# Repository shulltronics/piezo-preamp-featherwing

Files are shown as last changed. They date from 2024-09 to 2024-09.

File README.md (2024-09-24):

Piezo Preamp FeatherWing
=========================================

### By Carsten Thue-Bludworth, September 2024

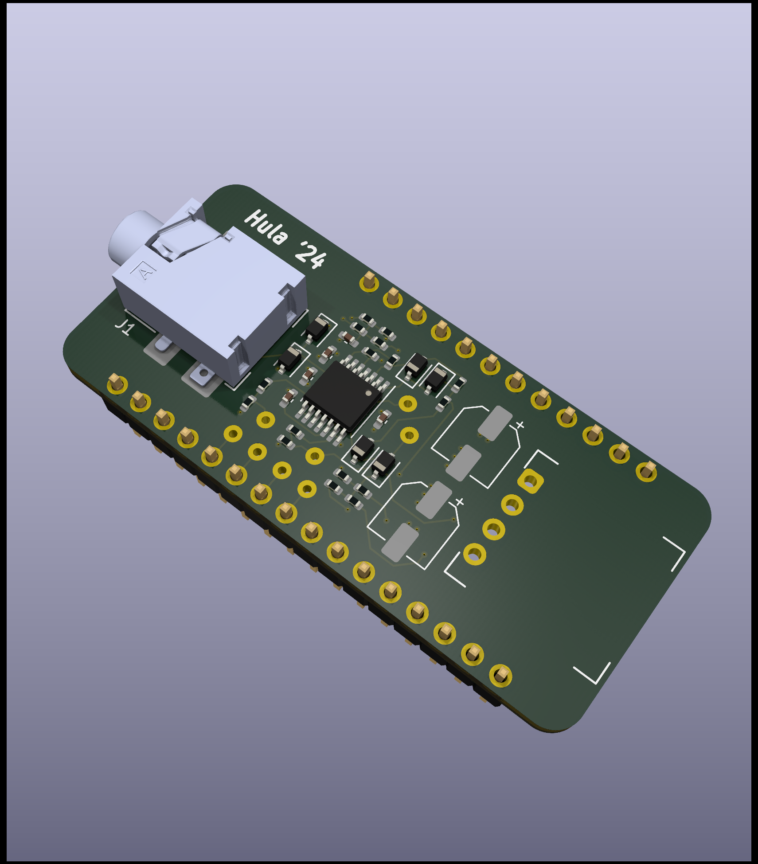
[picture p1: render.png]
board render


This featherwing provides a high-impedance gain stage and a simple envelope follower for piezo contact microphones.

The piezo is connected via a standard 3.5mm TRS shielded audio connector with the following pinout:
 - Tip: piezo signal
 - Ring: piezo ground
 - Sleeve: cable shield (not connected on piezo end)

The board requires a bipolar +12V/-12V power supply, provided via a 4pos Molex SL connector with the following pinout:
 - 1: +12V
 - 2: GND
 - 3: -12V
 - 4: signal out (default to unattenuated envelope follower signal).

Jumpers and plated holes are provided to configure which signals are sent to which pins.
* By default, the SL connector gets the unattenuated envelope follower signal.
* By default, no analog pins on the feather headers are connected. Use wire jumpers to connect signals to the analog pins you want to use.
* Jumpers can configure the amplifier stage gain, as well as the envelope follower decay time. By default, the gain is 100x and the decay is set with a 270k resistor.

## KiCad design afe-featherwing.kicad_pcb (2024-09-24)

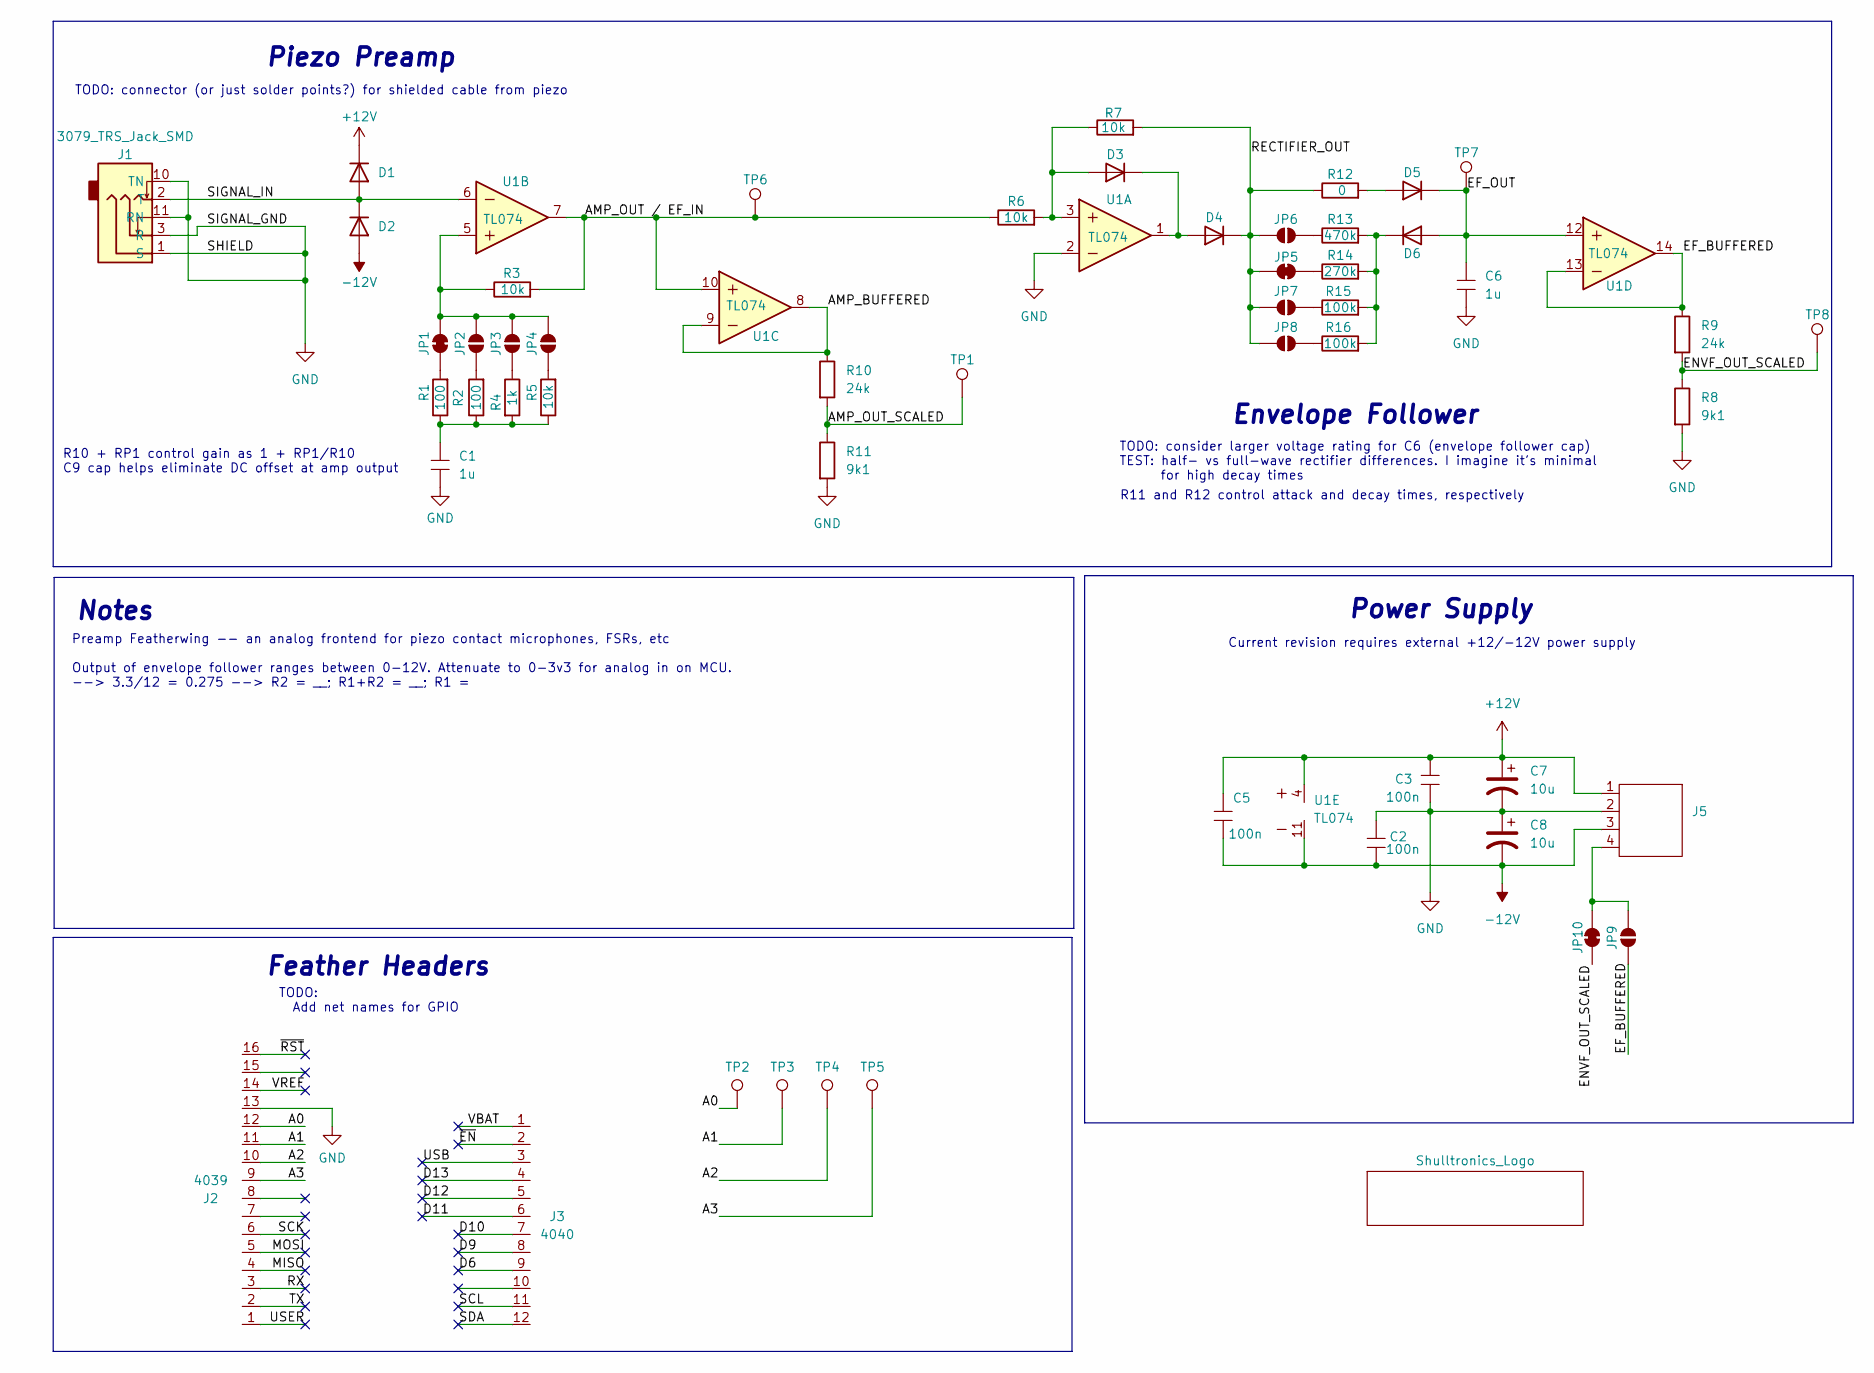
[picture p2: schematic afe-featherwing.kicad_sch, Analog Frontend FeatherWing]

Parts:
C1, C6: 4013_Capacitor_1u_16V_0402; C_0402_HandSolder
C2, C3, C5: 3089_Capacitor_100n_16V_0402; C_0402_HandSolder
C7, C8: 4031_Capacitor_10u_35V_SMD; 3088_Capacitor_10u_50V_SMD
D1, D2, D3, D4, D5, D6: 1N4148W; D_SOD-323
J1: 3079_TRS_Jack_SMD
J2: 4039_Header_Male_Vert_16pin_0.1in; 4039_Header_16pos_2.54mm
J3: 4040_Header_Male_Vert_12pin_0.1in; 4040_Header_12pos_2.54mm
J5: 3033_Connector_SL_4pos_RA; 3033_Molex_SL_4pos_RA
JP1: 100; SolderJumper-2_P1.3mm_Bridged_Pad1.0x1.5mm
JP2: 100; SolderJumper-2_P1.3mm_Open_TrianglePad1.0x1.5mm
JP3: 1k; SolderJumper-2_P1.3mm_Open_TrianglePad1.0x1.5mm
JP4: 10k; SolderJumper-2_P1.3mm_Open_TrianglePad1.0x1.5mm
JP5: 270k; SolderJumper-2_P1.3mm_Bridged_Pad1.0x1.5mm
JP6: 470k; SolderJumper-2_P1.3mm_Open_TrianglePad1.0x1.5mm
JP7, JP8: 100k; SolderJumper-2_P1.3mm_Open_TrianglePad1.0x1.5mm
JP9: EF_BUF; SolderJumper-2_P1.3mm_Open_TrianglePad1.0x1.5mm
JP10: EF_ATN; SolderJumper-2_P1.3mm_Bridged_Pad1.0x1.5mm
L1: Shulltronics_Logo
R1, R2: 4038_Resistor_SMD_100_0.125W_1%; RES-0402
R3, R5, R6, R7: 4008_Resistor_SMD_10k_0.125W_1%; RES-0402
R4: 4010_Resistor_SMD_1k_0.125W_1%; RES-0402
R8, R11: 4082_Resistor_SMD_9k1_1/16W_1%; RES-0402
R9, R10: 4083_Resistor_SMD_24k_1/16W_1%; RES-0402
R12: 4021_Resistor_SMD_Jumper; RES-0402
R13: 4080_Resistor_SMD_470k_0.125W_1%; RES-0402
R14: 4019_Resistor_SMD_270k_0.125W_1%; RES-0402
R15, R16: 4017_Resistor_SMD_100k_0.125W_1%_1; RES-0402
TP1: AMP_ATN; TestPoint_THTPad_D1.5mm_Drill0.7mm
TP2: A0; TestPoint_THTPad_D1.5mm_Drill0.7mm
TP3: A1; TestPoint_THTPad_D1.5mm_Drill0.7mm
TP4: A2; TestPoint_THTPad_D1.5mm_Drill0.7mm
TP5: A3; TestPoint_THTPad_D1.5mm_Drill0.7mm
TP6: AMP_OUT; TestPoint_THTPad_D1.5mm_Drill0.7mm
TP7: EF_BUF; TestPoint_THTPad_D1.5mm_Drill0.7mm
TP8: EF_ATN; TestPoint_THTPad_D1.5mm_Drill0.7mm
U1: 3099_TL074CPW_SMD; 3099_TL074CPW_TSSOP14

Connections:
+12V: C3.2, C5.2, C7.1, D1.1 (K), J5.1, U1.4 (VCC)
-12V: C2.1, C5.1, C8.2, D2.2 (A), J5.3, U1.11 (VEE)
/A0: J2.12, TP2.1
/A1: J2.11, TP3.1
/A2: J2.10, TP4.1
/A3: J2.9, TP5.1
/AMP_BUFFERED: R10.1, U1.8 (3OUT), U1.9 (3IN-)
/AMP_OUT / EF_IN: R3.2, R6.1, TP6.1, U1.7 (2OUT), U1.10 (3IN+)
/AMP_OUT_SCALED: R10.2, R11.1, TP1.1
/D6: J3.9
/D9: J3.8
/D10: J3.7
/D11: J3.6
/D12: J3.5
/D13: J3.4
/EF_BUFFERED: JP9.1 (A), R9.1, U1.13 (4IN-), U1.14 (4OUT)
/EF_OUT: C6.2, D5.1 (K), D6.2 (A), TP7.1, U1.12 (4IN+)
/ENVF_OUT_SCALED: JP10.1 (A), R8.1, R9.2, TP8.1
/MISO: J2.4
/MOSI: J2.5
/RECTIFIER_OUT: D4.1 (K), JP5.1 (A), JP6.1 (A), JP7.1 (A), JP8.1 (A), R7.2, R12.1
/RX: J2.3
/SCK: J2.6
/SCL: J3.11
/SDA: J3.12
/SIGNAL_IN: D1.2 (A), D2.1 (K), J1.2 (T), U1.6 (2IN-)
/TX: J2.2
/USB: J3.3
/USER: J2.1
/VBAT: J3.1
/VREF: J2.14
/~EN: J3.2
/~RST: J2.16
GND: C1.1, C2.2, C3.1, C6.1, C7.2, C8.1, J1.1 (S), J1.3 (R), J1.10 (TN), J1.11 (RN), J2.13, J5.2, R8.2, R11.2, U1.2 (1IN-)
unnamed: C1.2, R1.1, R2.1, R4.2, R5.1
unnamed: D3.2 (A), R6.2, R7.1, U1.3 (1IN+)
unnamed: D3.1 (K), D4.2 (A), U1.1 (1OUT)
unnamed: D5.2 (A), R12.2
unnamed: D6.1 (K), R13.2, R14.2, R15.2, R16.2
unnamed: JP1.1 (A), R1.2
unnamed: JP1.2 (B), JP2.2 (B), JP3.2 (B), JP4.2 (B), R3.1, U1.5 (2IN+)
unnamed: JP2.1 (A), R2.2
unnamed: JP3.1 (A), R4.1
unnamed: JP4.1 (A), R5.2
unnamed: JP5.2 (B), R14.1
unnamed: JP6.2 (B), R13.1
unnamed: JP7.2 (B), R15.1
unnamed: JP8.2 (B), R16.1
unnamed: J5.4, JP9.2 (B), JP10.2 (B)

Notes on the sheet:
Notes
TODO: Add net names for GPIO
Envelope Follower
Piezo Preamp
Power Supply
Preamp Featherwing -- an analog frontend for piezo contact microphones, FSRs, etc Output of envelope follower ranges between 0-12V. Attenuate to 0-3v3 for analog in on MCU. --> 3.3/12 = 0.275 --> R2 = __; R1+R2 = __; R1 =
Feather Headers
TODO: consider larger voltage rating for C6 (envelope follower cap) TEST: half- vs full-wave rectifier differences. I imagine it's minimal for high decay times
Current revision requires external +12/-12V power supply
R11 and R12 control attack and decay times, respectively
TODO: connector (or just solder points?) for shielded cable from piezo
R10 + RP1 control gain as 1 + RP1/R10 C9 cap helps eliminate DC offset at amp output

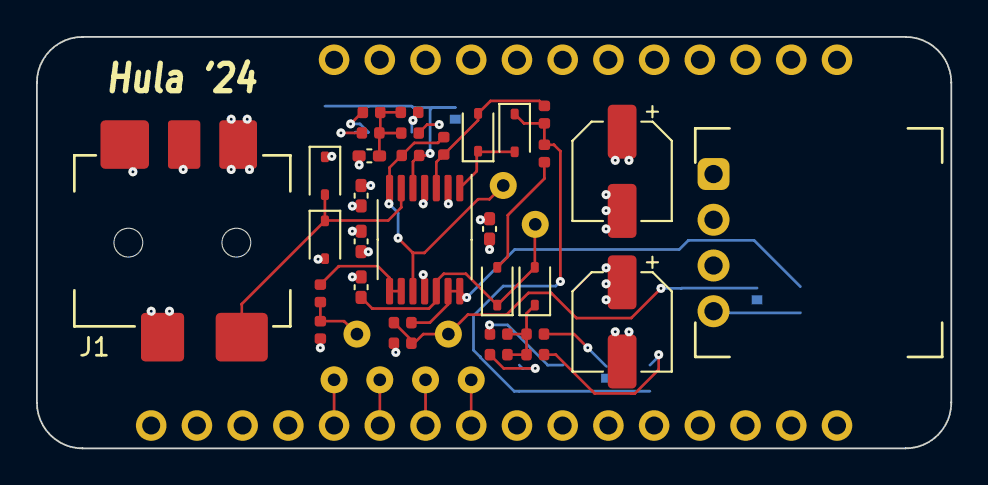
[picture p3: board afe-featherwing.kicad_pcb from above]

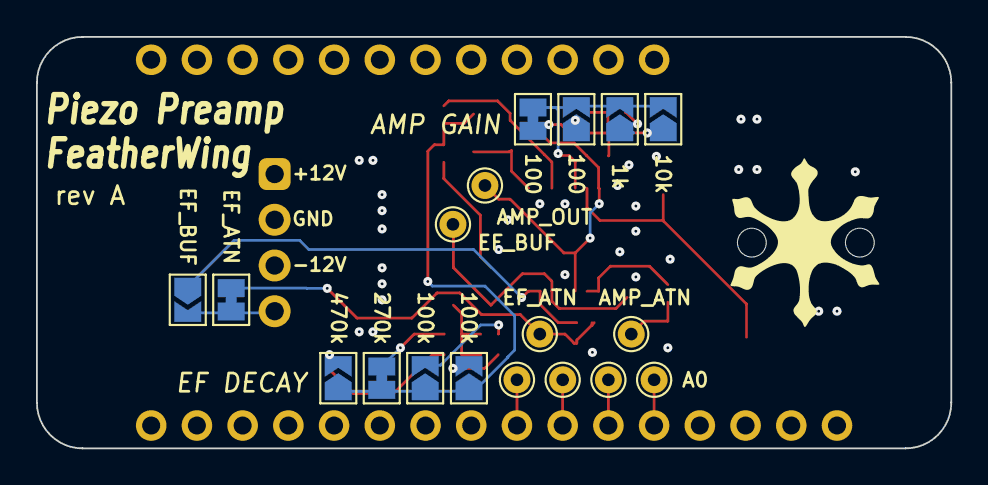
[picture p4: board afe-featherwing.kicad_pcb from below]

Board: 4 copper layers, 50.8 x 22.9 mm, 53 parts (18 on the bottom side), 30 nets.
